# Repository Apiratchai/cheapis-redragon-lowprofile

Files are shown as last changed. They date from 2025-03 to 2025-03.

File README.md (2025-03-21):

```mermaid
graph TD;

subgraph In_Progress
  id1["Cherry MX, Kailh Choc V1"] --> id2["Redragon Low Profile (reversible)"] --> id3["All MX, Kailh Choc V1, Redragon low profile switches support (In Branch)"];

end

subgraph To_Do
  A["Laser cut switch-bottom plates (minimalist, full plate, etc)"];
  B["space bar bridged version"];
  C["mill max 0305 compatability test"];
  D["Encoders or more switches n the thumb cluster"]

end

```
- Kicad 9.0 or newer maybe required
- This project aims to change only the switch being used while minimizing changes to everything else to maintain the best compatibility.
- This is my first time using KiCad. May you and the Lord forgive me if files contain any mistakes or issues (It's the reason why I remove the support for both MX and Choc V1, I wasn't sure if I can make it work).
- [Redragon Low Profile footprint]( https://github.com/rgoulter/keyboard-labs/blob/master/pcb/ProjectLocal.pretty/SW_Redragon_LowProfile_PCB_1.00u.kicad_mod
) is from  [Rgoulter](https://github.com/rgoulter). Kudos to this man.

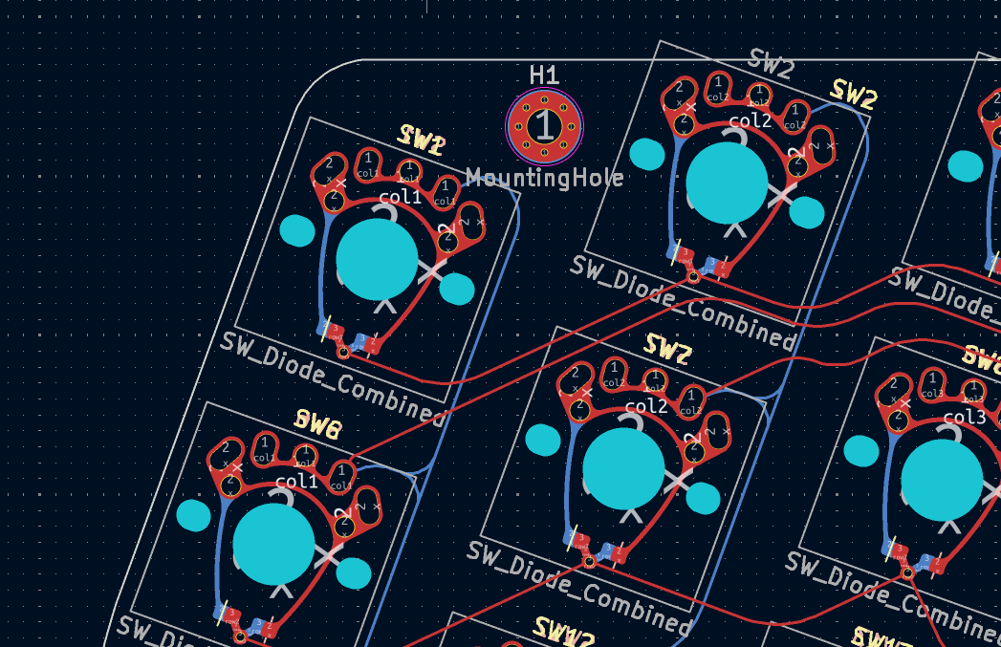
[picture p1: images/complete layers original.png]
complete layers original

Original PCB
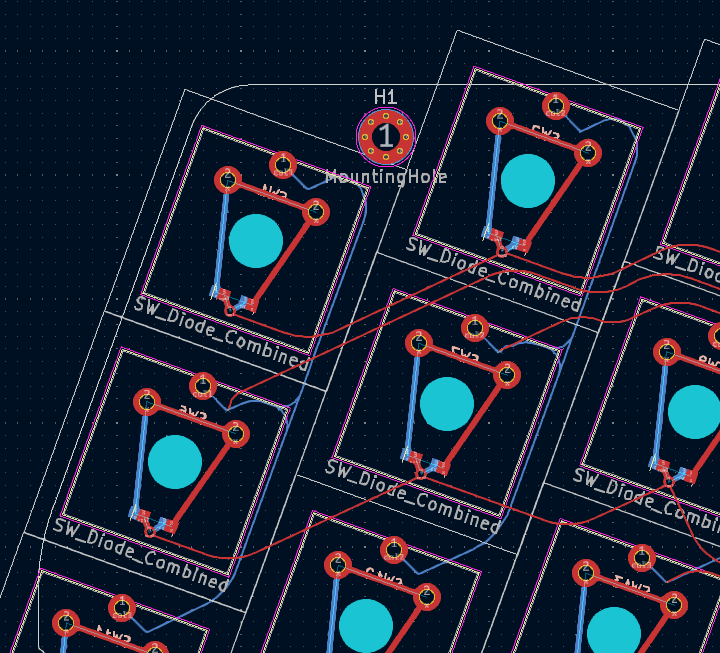
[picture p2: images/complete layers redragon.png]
complete layers red dragon

Redragon PCB
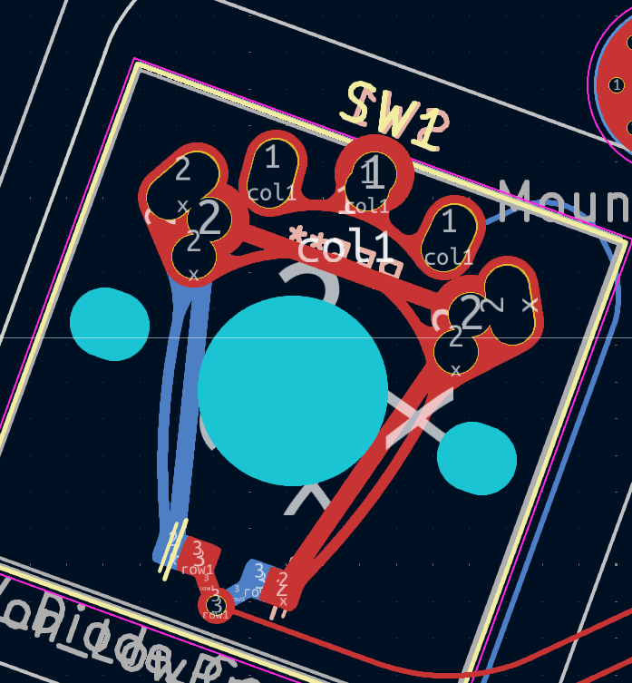
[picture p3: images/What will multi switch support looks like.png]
for blind people, I just put redragon footprint on top of the old design

If I just put redragon footprint on top of the old design, I think this will work with minimal change to the number 2 pad (make it smaller ?) I will try, 2$ per order anyway.
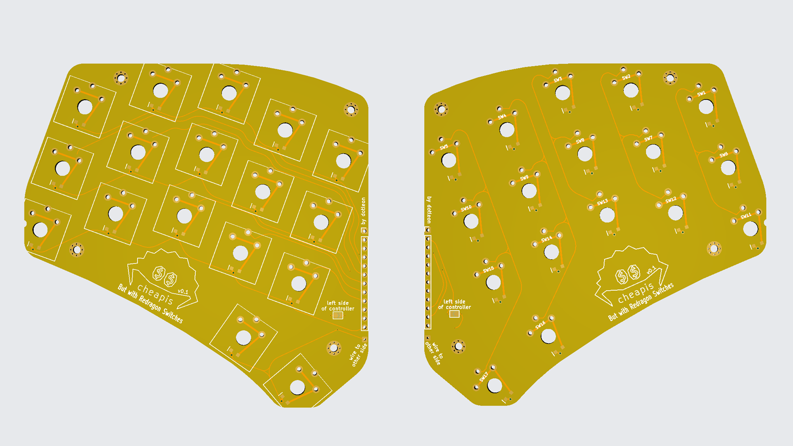
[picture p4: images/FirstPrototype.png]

First Protorype I ordered on JLCPCB. If you notice the wires not connected, it has been fixed (maybe).

# cheapis (The Original)

v0.1 issues:
- most ubs cables cannot be plugged in when the pro micro is soldered in an usual way (upright, with the usually included pins), because of the top middle buttons. It has to be solderes upside down, flush with the keyboard pcb.
- not really an issue, but SOD-323 diodes are challenging to solder. They're also not the cheapest, although the difference is minuscule.

Cheapis was inspired by ferris and sweep.

It is the cheapest alternative to the above keyboards (that still has a PCB) as it is sub 100x100mm in size so it can be ordered for a very low price and it only needs one controller (Pro Micro or alternative).

cheapis keyboard! cheapis keyboard built

cheapis keyboard! cheapis keyboard

Specs:
- Split
- Unibody
- 34 key
- Compatible with MX, Kailh Choc v1 and Gateron low profile switches
- needs 1n4148 SOD-323 diodes
- 19mm standard spacing
- angled sides by 20 degree

Pros:
- less than 100x100mm
- reversible, so you can order less
- needs ony one Pro Micro or alternative
- very cheap way to experiment with 34 key layout

Cons:
- it has to be unibody
- tenting is not possible
- fragile without a plate as the Pro Micro keeps the two sides together
- not much features, it's hardly more than a hardwire

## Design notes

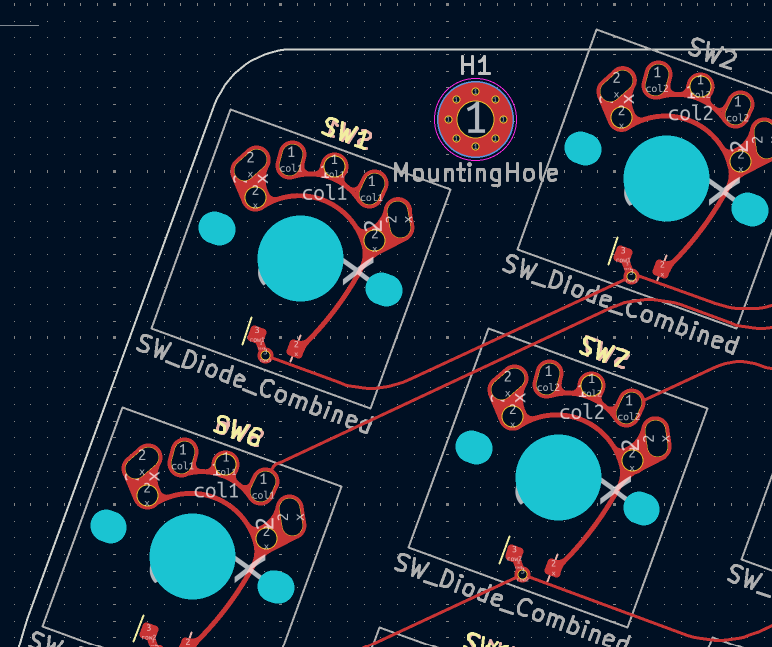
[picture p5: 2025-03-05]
images/front layer original.png

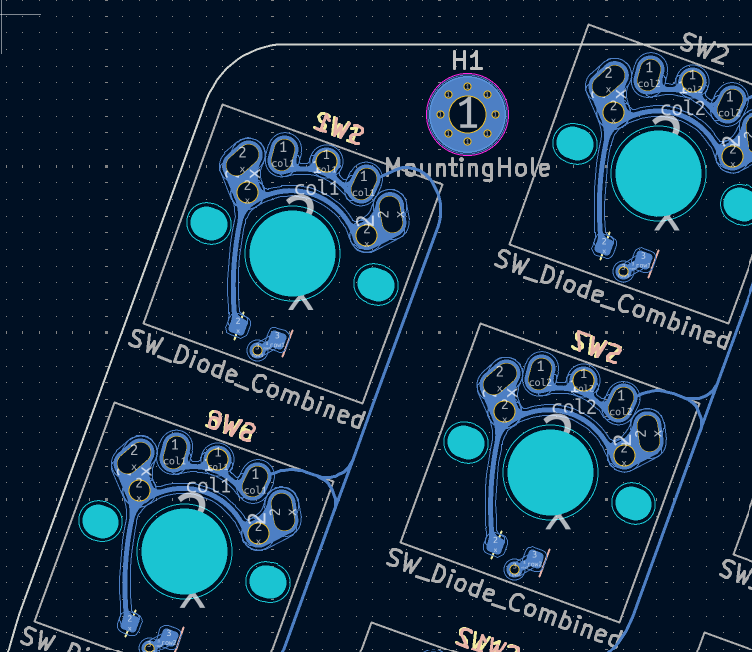
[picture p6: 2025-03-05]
images/back layer original.png

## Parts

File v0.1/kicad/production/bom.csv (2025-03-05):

Designator | Footprint | Quantity | Value | LCSC Part #
H1, H2, H3, H4 | MountingHole_2.2mm_M2_Pad_Via | 4 | MountingHole
J1 | SolderWire-0.1sqmm_1x01_D0.4mm_OD1mm | 1 | Conn_01x01
JP1, JP2 | SolderJumper-2_P1.3mm_Open_TrianglePad1.0x1.5mm | 2 | SolderJumper_2_Open
SW1, SW10, SW11, SW12, SW13, SW14, SW15, SW16, SW17, SW2, SW3, SW4, SW5, SW6, SW7, SW8, SW9 | SW_Redragon_LowProfile_PCB_1.00u | 17 | SW_Diode_Combined
U1 | promicro_half | 1 | ProMicro

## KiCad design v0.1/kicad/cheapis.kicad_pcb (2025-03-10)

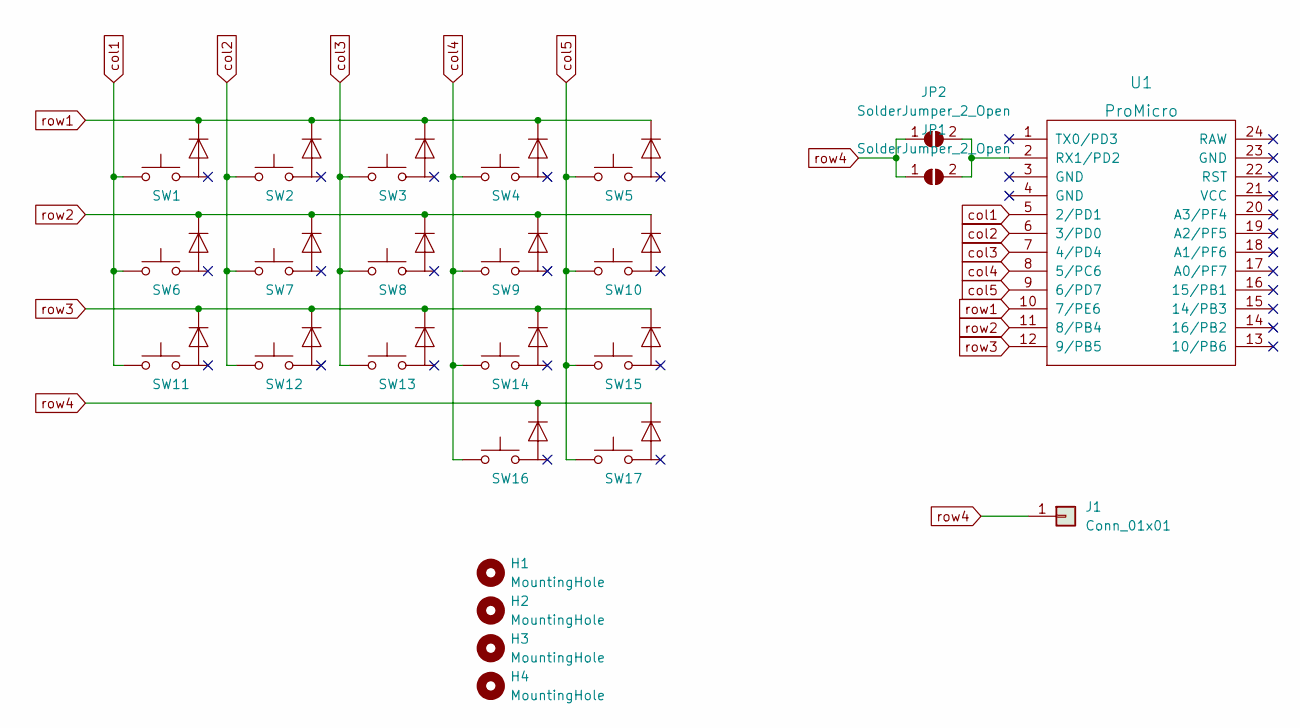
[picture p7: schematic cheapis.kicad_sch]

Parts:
H1, H2, H3, H4: MountingHole; MountingHole_2.2mm_M2_Pad_Via
J1: Conn_01x01; SolderWire-0.1sqmm_1x01_D0.4mm_OD1mm
JP1, JP2: SolderJumper_2_Open; SolderJumper-2_P1.3mm_Open_TrianglePad1.0x1.5mm
SW1, SW2, SW3, SW4, SW5, SW6, SW7, SW8, SW9, SW10, SW11, SW12, SW13, SW14, SW15, SW16, SW17: SW_Diode_Combined; SW_Redragon_LowProfile_PCB_1.00u
U1: ProMicro; promicro_half

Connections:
unnamed: JP1.2 (B), JP2.2 (B), U1.2 (RX1/PD2)
col1: SW1.1, SW6.1, SW11.1, U1.5 (2/PD1)
col2: SW2.1, SW7.1, SW12.1, U1.6 (3/PD0)
col3: SW3.1, SW8.1, SW13.1, U1.7 (4/PD4)
col4: SW4.1, SW9.1, SW14.1, SW16.1, U1.8 (5/PC6)
col5: SW5.1, SW10.1, SW15.1, SW17.1, U1.9 (6/PD7)
row1: SW1.3, SW2.3, SW3.3, SW4.3, SW5.3, U1.10 (7/PE6)
row2: SW6.3, SW7.3, SW8.3, SW9.3, SW10.3, U1.11 (8/PB4)
row3: SW11.3, SW12.3, SW13.3, SW14.3, SW15.3, U1.12 (9/PB5)
row4: J1.1, JP1.1 (A), JP2.1 (A), SW16.3, SW17.3

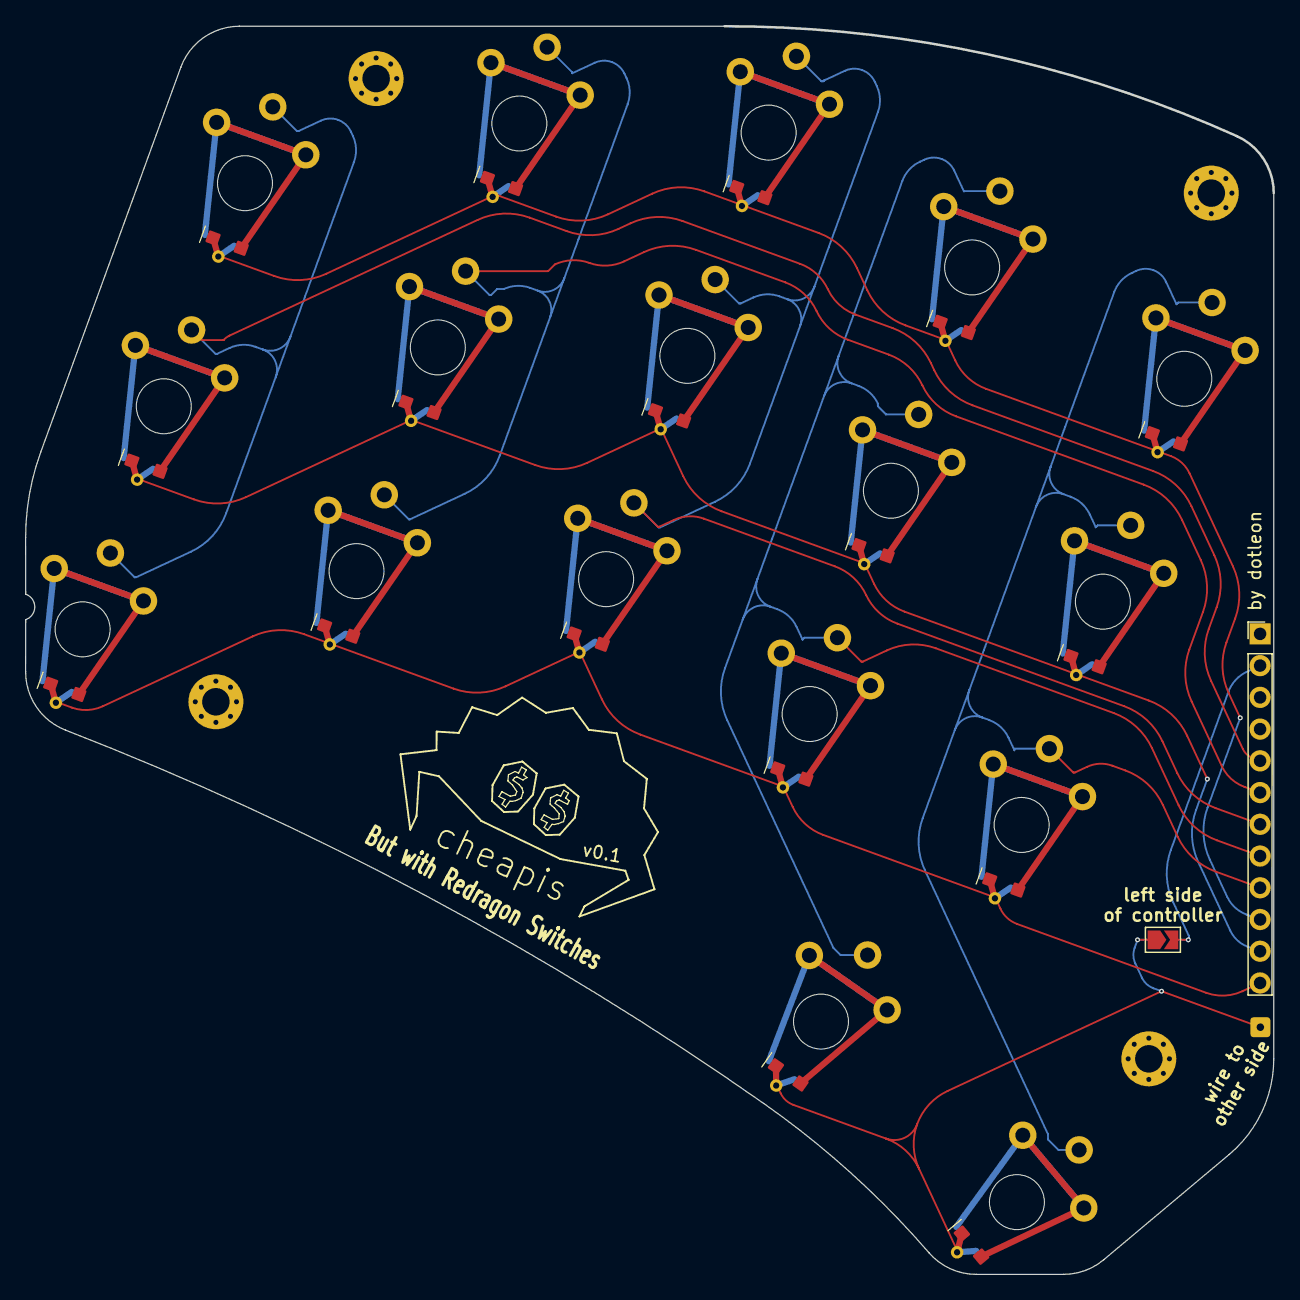
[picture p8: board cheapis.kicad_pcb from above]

Board: 2 copper layers, 99.9 x 99.9 mm, 25 parts (1 on the bottom side), 10 nets.

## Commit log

2025-03-05 add customized SW_Redragon_LowProfile_1.00u footprint
    [cheapis.kicad_pcb, cheapis.kicad_sch]
2025-03-05 first prototype design
    [bom.csv, cheapis.kicad_sch, designators.csv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]
2025-03-10 add .gitignore
    [cheapis.kicad_pcb]
2025-03-10 fix some major design problem, rows not fully connected
    [bom.csv, cheapis.kicad_pcb, designators.csv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]
